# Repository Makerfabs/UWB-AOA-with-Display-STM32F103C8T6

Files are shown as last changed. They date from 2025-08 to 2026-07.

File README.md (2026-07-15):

# UWB-AOA-with-Display-STM32F103C8T6

UWB AOA with Display STM32F103C8T6

# Makerfabs

[Makerfabs Homepage](https://www.makerfabs.com/)

[Makerfabs Wiki](https://wiki.makerfabs.com/)

# Feature:

• Controller: STM32F103C8T6, max 72MHz frequency, 1.25 DMIPS/MHz(Dhrystone 2.1), 64KB Flash memory, 20KB SRAM  

• DW3000 Module(Anchor):UWB-X3-AOA  

• DW3000 Module(Tag):UWB-X3-MAX  

• OLED: 1.3" SSD1306, 128X64, I2C  

• "Zero" Dropout: On board ideal diode circuit  

• Dual-USB Type C:USB-Native/USB-TTL  

• USB-to-UART: CH340K  

• Charger: TP4056  

• Button:RST/BTN  

• Expander: 2X12 2.54mm header  

• Open Source: hardware/firmware/software  

• Coverage radius: 30m@6.8M 

• angle:+/-60° 

• angle error:±5° 

• Ranging error:< 10cm 

• Positioning error： <10cm 

• Frequency: CH5 (6.5 GHz)/CH9 (8 GHz)  

• Speed rate: 850 Kbps/6.8Mbps  

• Communication interface: SPI  

• Power Supply: USB 5.0V or 3.7V lithium battery  

# Usage:

1. Insert to USB-NATIVE port of AOA anchor.  
2. Insert to USB-TTL port of AOA tag(Or Powered by Li-battery).  
3. Open the AOA System Application.  
4. Select Tag ID and joined.  
5. Result Show:  
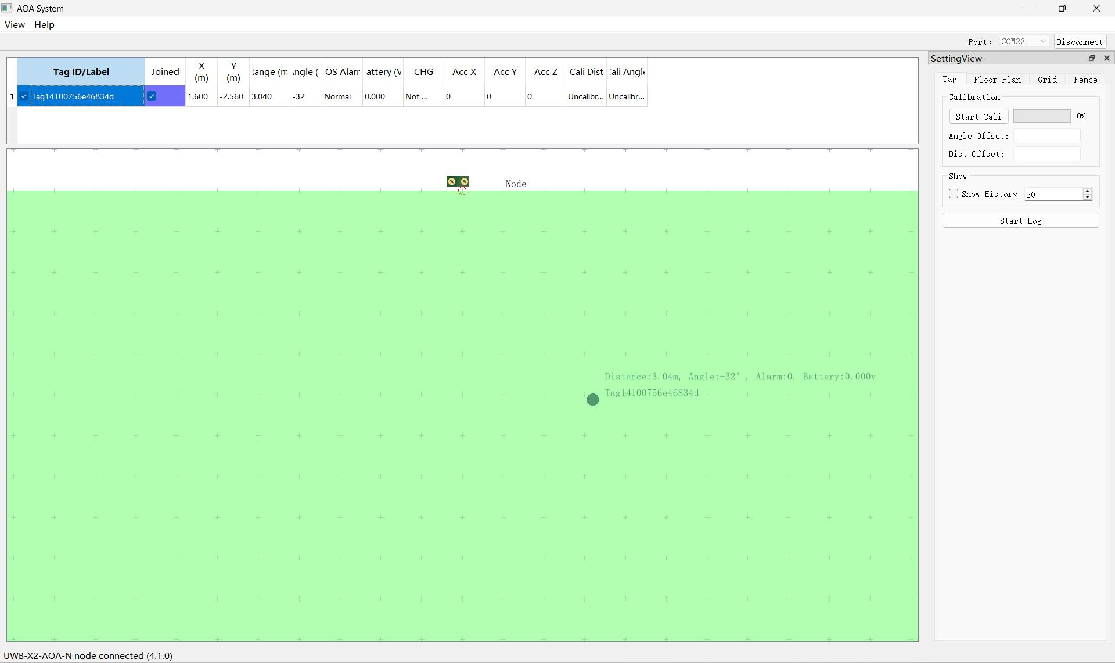
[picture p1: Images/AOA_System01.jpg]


# Firmware

| Type | Default Firmware | 
|---|---|
| Anchor | Project\_Anchor\_v1.0.hex |
| Tag | Project\_Tag\_v1.0.hex |

# How to Program?

|ST-LINK V2 |AOA Anchor/Tag Board|  
| ---- | ---- |
|SWCLK|SWCK|  
|SWDIO|SWIO|  
|GND|GND|  
|3.3V|+3.3V|  

# How to turn on the PA in tag?
1. Modify the value of PMSC_TXFINESEQ_DISABLE to 0x0d20010 in deca_vals.h header file: 

#define PMSC_TXFINESEQ_DISABLE  0x0d20010 

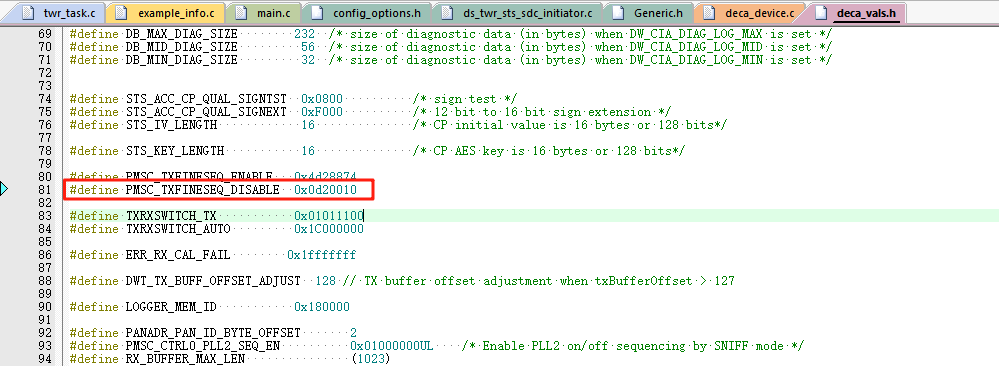
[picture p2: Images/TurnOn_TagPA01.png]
  

2. Add a definition in config_options.h header file: 

#define HW_PA 

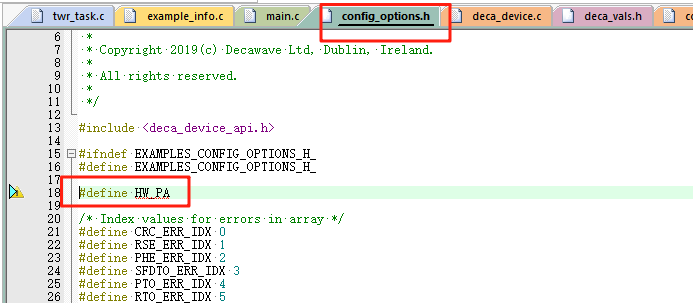
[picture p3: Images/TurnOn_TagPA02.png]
  

# Why there is No com port in AOA system software?  

1. Install the STM32_VCP_V1.4.0_Setup.exe in Driver folder.  
2. Update the driver from the Device Manager.  
3. Insert the USB Type C cable to USB Native port of AOA Anchor before you open the AOA system software. 

# Where to purchase? 
[AOA KIT](https://www.makerfabs.com/mauwb-stm32-aoa-development-kit.html) 

# FAQ

You can list your question here or contact techsupport@makerfabs.com for technology support. Detailed descriptions of your question will be helped to solve your question.

• Q:The AOA kit has multiple tag bindings, resulting in the inability to obtain distance and angle information.

• A:One AOA device only supports one anchor point paired with one tag to work simultaneously. Excess tags will cause the data not to be displayed. Please unbind the phantom false tags in the interface, and the kit can be used normally.

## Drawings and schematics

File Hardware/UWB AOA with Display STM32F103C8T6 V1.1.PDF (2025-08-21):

USB | Ideal Diode | OLED

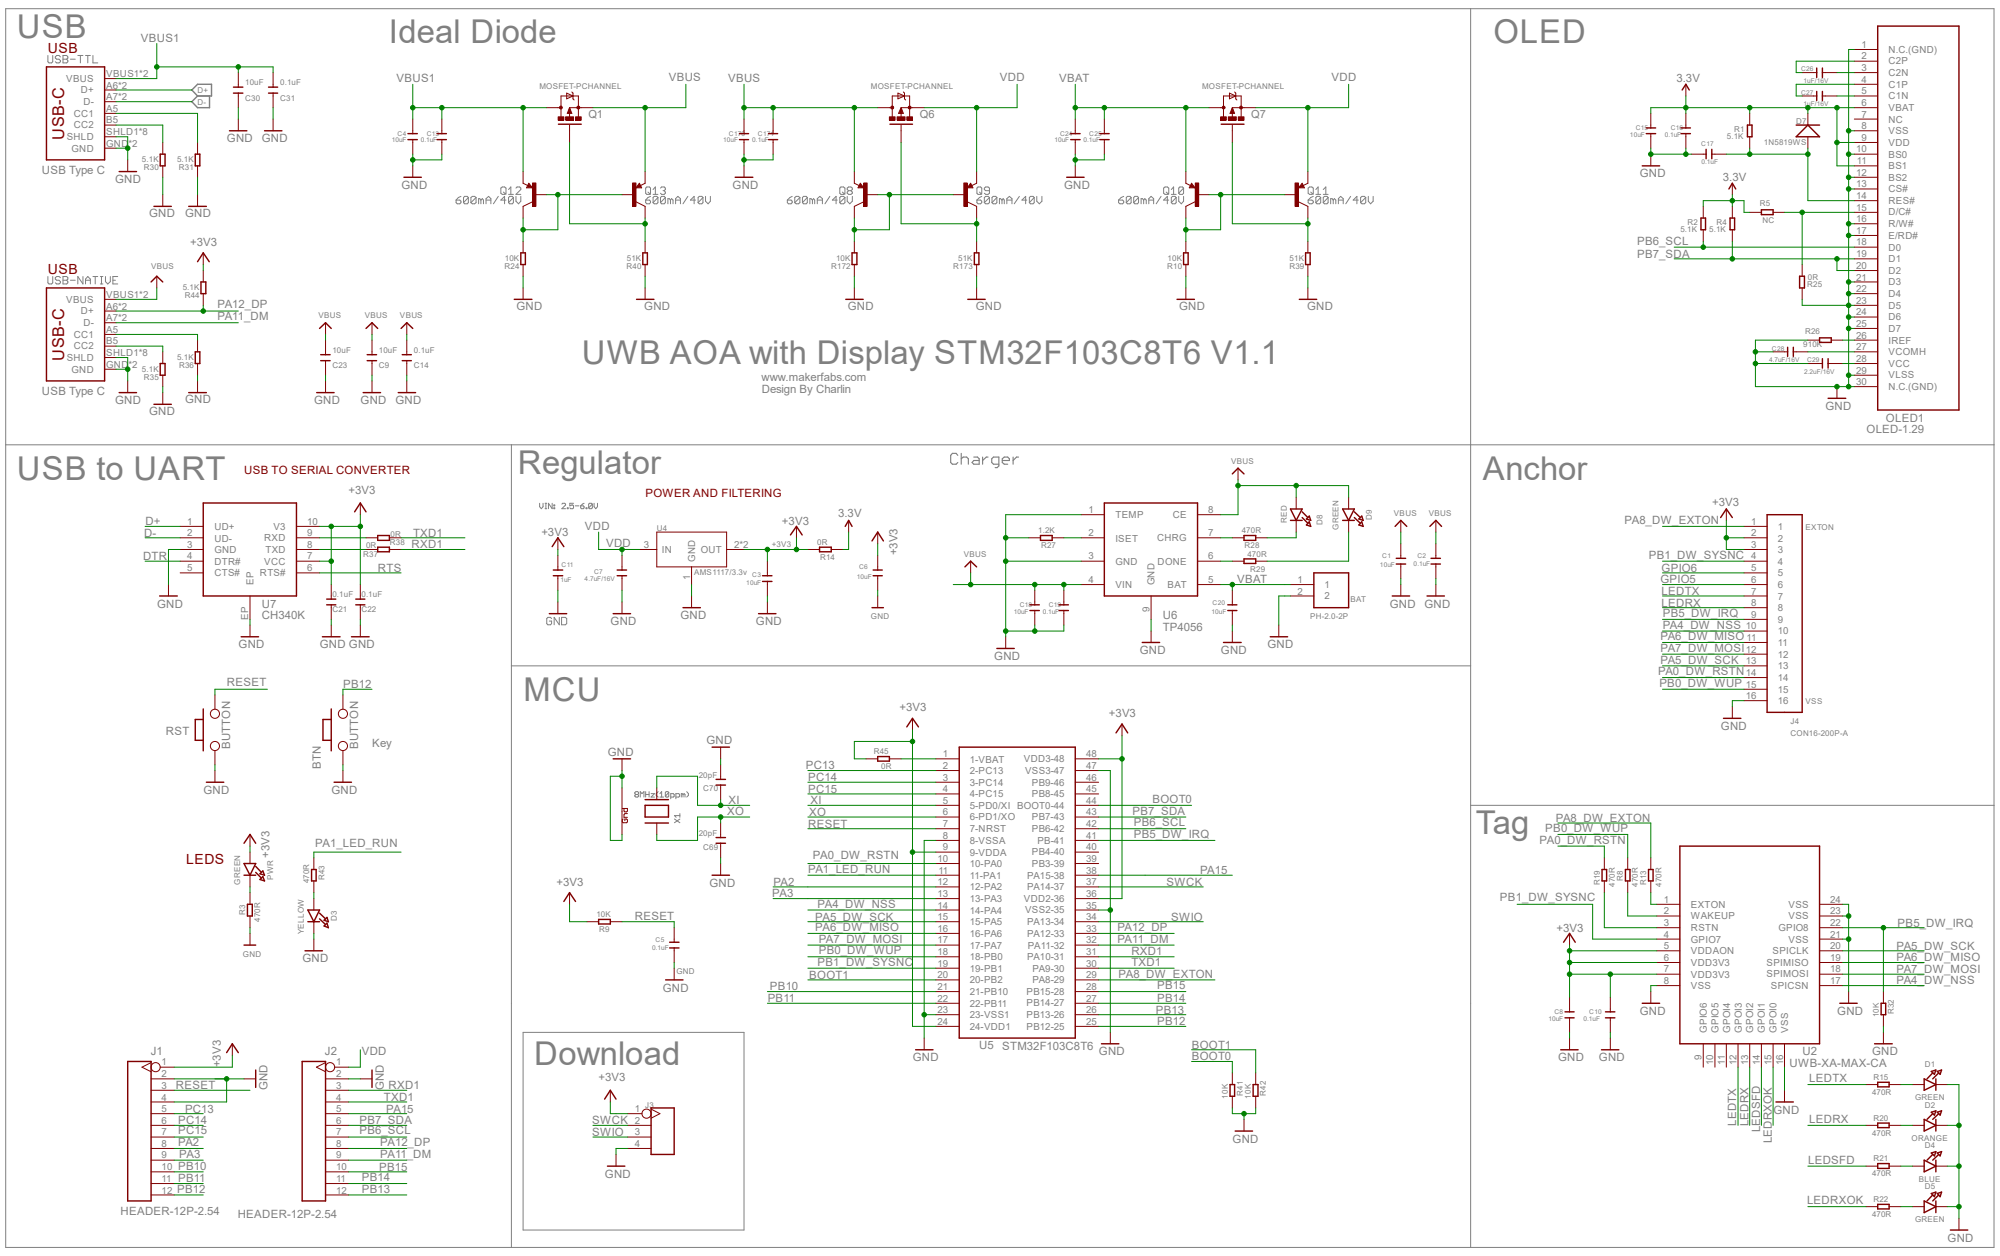
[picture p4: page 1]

VBUS1

USB TO SERIAL CONVERTER USB⁻C USB⁻C

D1 19
D2 20

UWB AOA with Display STM32F103C8T6 V1.1

4.7uF/16V C29 | VCC 28

2.2uF/16V | VLSS 29

11 PB11 | PB14 11
12 PB12 | 12 PB13

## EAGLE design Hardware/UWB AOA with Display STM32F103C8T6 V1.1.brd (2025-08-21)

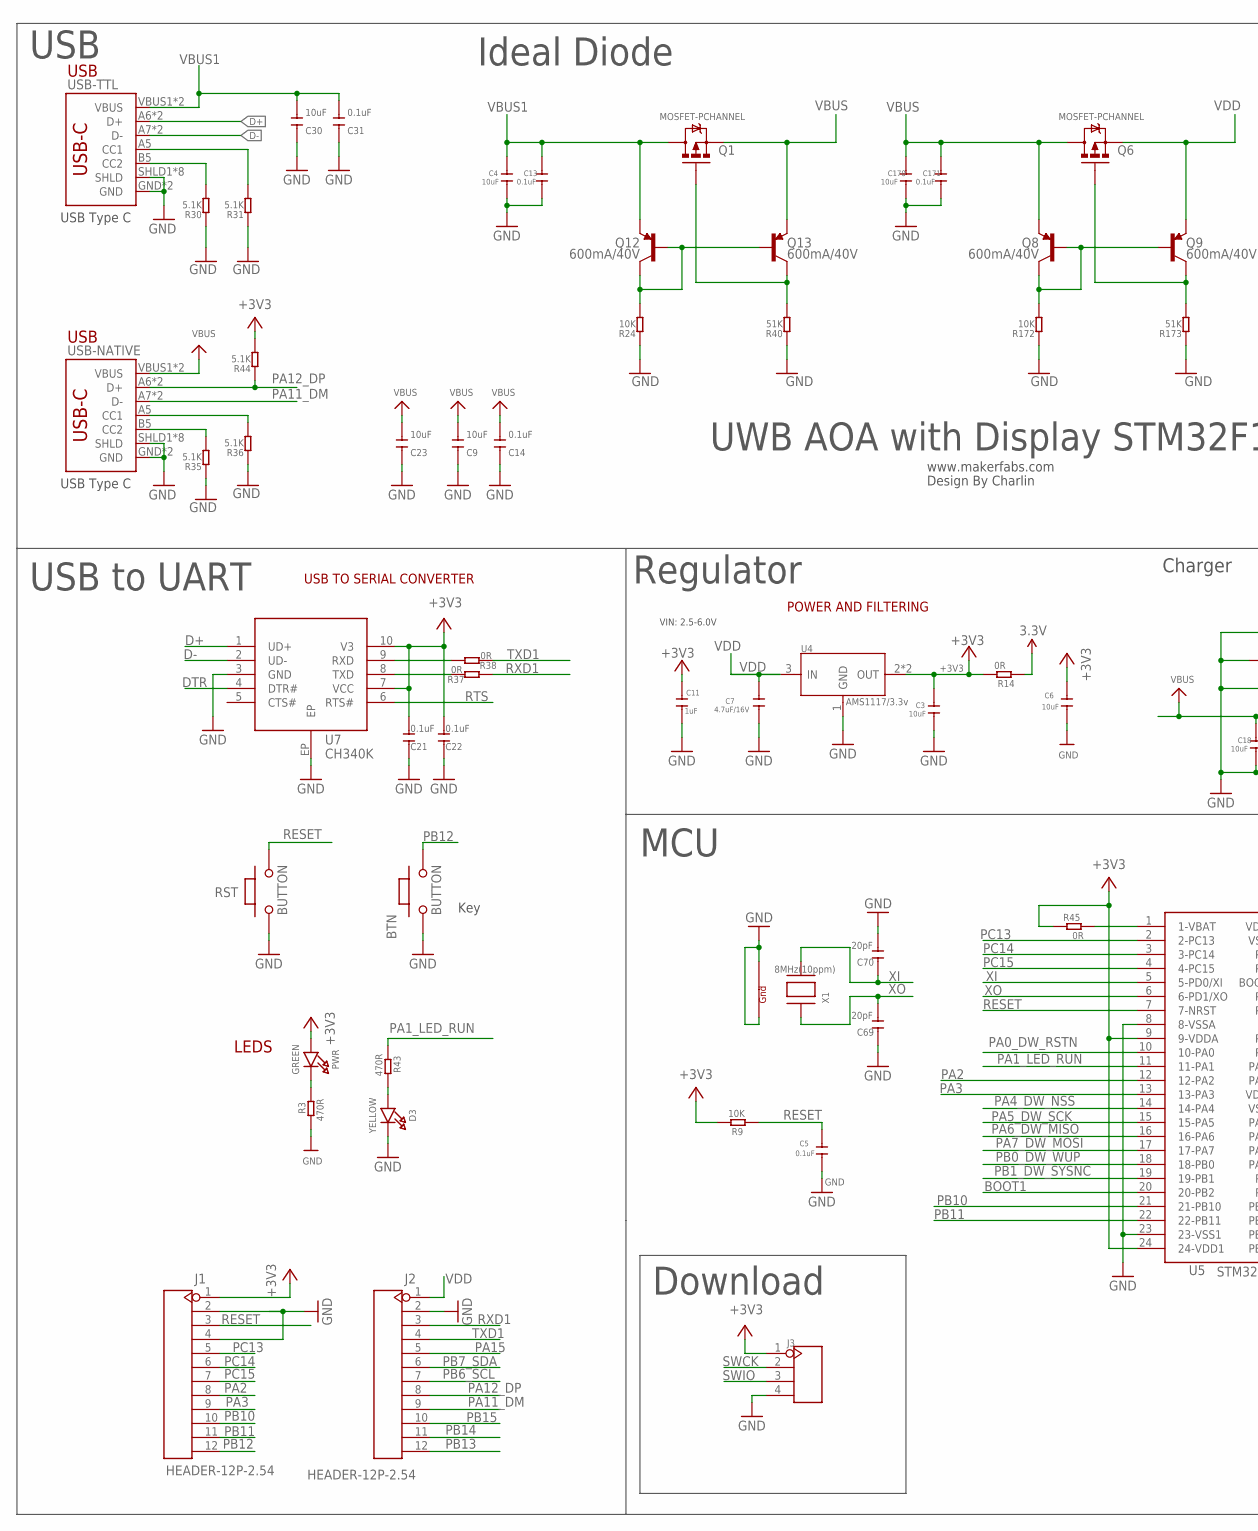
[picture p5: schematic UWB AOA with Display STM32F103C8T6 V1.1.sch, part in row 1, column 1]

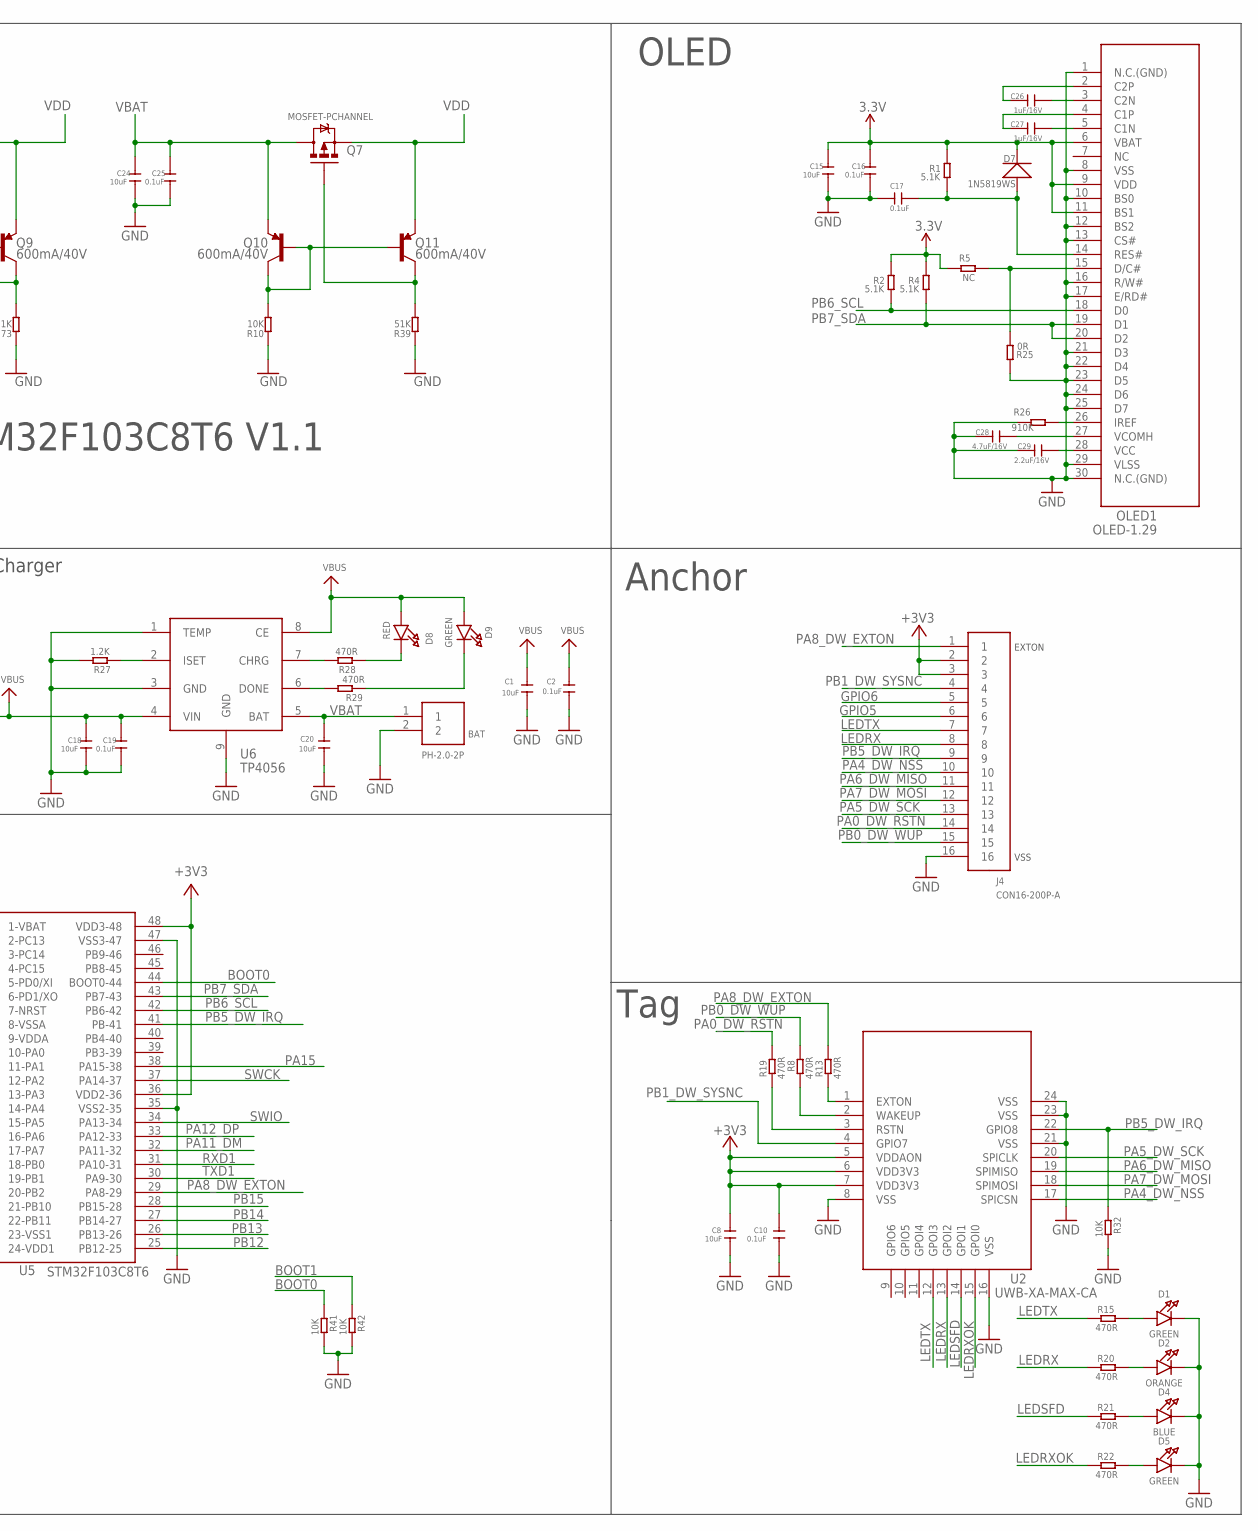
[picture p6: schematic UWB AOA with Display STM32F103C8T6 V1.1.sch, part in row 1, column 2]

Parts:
BAT: PH-2.0-2P
BTN: BUTTON; 157SW
C1, C3, C4, C6, C8, C15, C18, C20, C24, C170: 10uF; C0603
C2, C5, C10, C13, C16, C17, C19, C25, C171: 0.1uF; C0603
C7, C28: 4.7uF/16V; C0603
C9, C23, C30: 10uF; DISCRETE_C0603
C11: 1uF; C0603
C14, C21, C22, C31: 0.1uF; DISCRETE_C0603
C26, C27: 1uF/16V; C0603
C29: 2.2uF/16V; C0603
C69, C70: 20pF; DISCRETE_C0402
D1, D5, D9: GREEN; CHIPLED_0805_NOOUTLINE
D2: ORANGE; CHIPLED_0805_NOOUTLINE
D3: YELLOW; CHIPLED_0805_NOOUTLINE
D4: BLUE; CHIPLED_0805_NOOUTLINE
D7: 1N5819WS; SOD323
D8: RED; CHIPLED_0805_NOOUTLINE
J1, J2: HEADER-12P-2.54; 12P-2.54
J3: HEADER-4P-60/35MILROUND; 4P-65/35ROUND
J4: CON16-200P-A; THD16-200P-3250L240W430H
OLED1: OLED-1.29
PWR: GREEN; CHIPLED_0805_NOOUTLINE
Q1, Q6, Q7: MOSFET-PCHANNEL; SOT23-3
Q8, Q9, Q10, Q11, Q12, Q13: 600mA/40V; SOT23-3
R1, R2, R4: 5.1K; R0603
R3, R8, R13, R15, R19, R20, R21, R22, R28, R29, R43: 470R; R0603
R5: NC; R0603
R9, R32, R41, R42: 10K; R0603
R10, R24, R172: 10K; DISCRETE_R0603
R14, R25, R37, R38, R45: 0R; R0603
R26: 910K; R0603
R27: 1.2K; R0603
R30, R31, R35, R36, R44: 5.1K; DISCRETE_R0603
R39, R40, R173: 51K; DISCRETE_R0603
RST: BUTTON; 157SW
U2: UWB-XA-MAX-CA; UWB-X1-MAK-CA
U4: AMS1117/3.3v; SOT89
U5: STM32F103C8T6; LQFP48-50P-900L900W160H
U6: TP4056; SOP8-1.27P
U7: CH340K; ESOP-10-EP-150MIL
USB-NATIVE: USB_C5; USB-C-16P-5
USB-TTL: USB_C5; USB-C-16P-5
X1: 8MHz(10ppm); NX3225

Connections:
3.3V: C15.1, C16.1, D7.-, OLED1.6 (VBAT), OLED1.9 (VDD), OLED1.11 (BS1), R1.2, R2.2, R4.2, R5.2, R14.1
+3V3: C3.1, C6.1, C8.1, C10.1, C11.1, C21.2, C22.2, J1.1, J3.1, J4.2, J4.3, PWR.A, R9.2, R14.2, R44.2, R45.1, U2.5 (VDDAON), U2.6 (VDD3V3), U2.7 (VDD3V3), U4.2 (OUT), U4.4 (OUT), U5.9 (9-VDDA), U5.24 (24-VDD1), U5.36 (VDD2-36), U5.48 (VDD3-48), U7.7 (VCC), U7.10 (V3)
BOOT0: R41.1, U5.44 (BOOT0-44)
BOOT1: R42.1, U5.20 (20-PB2)
D+: U7.1 (UD+), USB-TTL.A6 (D+), USB-TTL.B6 (D+)
D-: U7.2 (UD-), USB-TTL.A7 (D-), USB-TTL.B7 (D-)
DTR: U7.4 (DTR#)
GND: BAT.2, BTN.1, C1.2, C2.2, C3.2, C4.2, C5.2, C6.2, C7.2, C8.2, C9.1, C10.2, C11.2, C13.2, C14.1, C15.2, C16.2, C17.1, C18.2, C19.2, C20.2, C21.1, C22.1, C23.1, C24.2, C25.2, C28.1, C29.1, C30.1, C31.1, C69.2, C70.1, C170.2, C171.2, D1.C, D2.C, D3.C, D4.C, D5.C, J1.2, J1.4, J2.2, J3.4, J4.16, OLED1.1 (N.C.(GND)), OLED1.8 (VSS), OLED1.10 (BS0), OLED1.12 (BS2), OLED1.13 (CS#), OLED1.16 (R/W#), OLED1.17 (E/RD#), OLED1.21 (D3), OLED1.22 (D4), OLED1.23 (D5), OLED1.24 (D6), OLED1.25 (D7), OLED1.29 (VLSS), OLED1.30 (N.C.(GND)), R3.1, R10.1, R24.1, R25.2, R26.2, R27.2, R30.1, R31.1, R32.2, R35.1, R36.1, R39.1, R40.1, R41.2, R42.2, R172.1, R173.1, RST.1, U2.8 (VSS), U2.16 (VSS), U2.21 (VSS), U2.23 (VSS), U2.24 (VSS), U4.1 (GND), U5.8 (8-VSSA), U5.23 (23-VSS1), U5.35 (VSS2-35), U5.47 (VSS3-47), U6.1 (TEMP), U6.3 (GND), U6.9 (GND), U7.3 (GND), U7.EP, USB-NATIVE.GND, USB-NATIVE.GND2 (GND), USB-NATIVE.SHLD1 (SHLD), USB-NATIVE.SHLD2 (SHLD), USB-NATIVE.SHLD3 (SHLD), USB-NATIVE.SHLD4 (SHLD), USB-NATIVE.SHLD5 (SHLD), USB-NATIVE.SHLD6 (SHLD), USB-NATIVE.SHLD7 (SHLD), USB-NATIVE.SHLD8 (SHLD), USB-TTL.GND, USB-TTL.GND2 (GND), USB-TTL.SHLD1 (SHLD), USB-TTL.SHLD2 (SHLD), USB-TTL.SHLD3 (SHLD), USB-TTL.SHLD4 (SHLD), USB-TTL.SHLD5 (SHLD), USB-TTL.SHLD6 (SHLD), USB-TTL.SHLD7 (SHLD), USB-TTL.SHLD8 (SHLD), X1.2 (G2), X1.4 (G1)
GPIO5: J4.6
GPIO6: J4.5
LEDRX: J4.8, R20.1, U2.13 (GPOI2)
LEDRXOK: R22.1, U2.15 (GPOI0)
LEDSFD: R21.1, U2.14 (GPOI1)
LEDTX: J4.7, R15.1, U2.12 (GPOI3)
unnamed: D1.A, R15.2
unnamed: C17.2, D7.+, OLED1.14 (RES#), R1.1
unnamed: OLED1.15 (D/C#), R5.1, R25.1
unnamed: PWR.C, R3.2
unnamed: C28.2, OLED1.27 (VCOMH)
unnamed: C26.2, OLED1.3 (C2N)
unnamed: C29.2, OLED1.28 (VCC)
unnamed: OLED1.26 (IREF), R26.1
unnamed: R13.1, U2.1 (EXTON)
unnamed: R8.1, U2.2 (WAKEUP)
unnamed: R19.1, U2.3 (RSTN)
unnamed: Q10.1 (B), Q10.3 (C), Q11.1 (B), R10.2
unnamed: D2.A, R20.2
unnamed: D4.A, R21.2
unnamed: D5.A, R22.2
unnamed: C26.1, OLED1.2 (C2P)
unnamed: C27.1, OLED1.4 (C1P)
unnamed: C27.2, OLED1.5 (C1N)
unnamed: R27.1, U6.2 (ISET)
unnamed: D3.A, R43.2
unnamed: R31.2, USB-TTL.A5 (CC1)
unnamed: R30.2, USB-TTL.B5 (CC2)
unnamed: R45.2, U5.1 (1-VBAT)
unnamed: R28.2, U6.7 (CHRG)
unnamed: R29.2, U6.6 (DONE)
unnamed: D8.C, R28.1
unnamed: D9.C, R29.1
unnamed: R36.2, USB-NATIVE.A5 (CC1)
unnamed: R35.2, USB-NATIVE.B5 (CC2)
unnamed: Q7.1 (G), Q11.3 (C), R39.2
unnamed: Q12.1 (B), Q12.3 (C), Q13.1 (B), R24.2
unnamed: Q1.1 (G), Q13.3 (C), R40.2
unnamed: R38.2, U7.9 (RXD)
unnamed: R37.2, U7.8 (TXD)
unnamed: Q8.1 (B), Q8.3 (C), Q9.1 (B), R172.2
unnamed: Q6.1 (G), Q9.3 (C), R173.2
PA0_DW_RSTN: J4.14, R19.2, U5.10 (10-PA0)
PA1_LED_RUN: R43.1, U5.11 (11-PA1)
PA2: J1.8, U5.12 (12-PA2)
PA3: J1.9, U5.13 (13-PA3)
PA4_DW_NSS: J4.10, U2.17 (SPICSN), U5.14 (14-PA4)
PA5_DW_SCK: J4.13, U2.20 (SPICLK), U5.15 (15-PA5)
PA6_DW_MISO: J4.11, U2.19 (SPIMISO), U5.16 (16-PA6)
PA7_DW_MOSI: J4.12, U2.18 (SPIMOSI), U5.17 (17-PA7)
PA8_DW_EXTON: J4.1, R13.2, U5.29 (PA8-29)
PA11_DM: J2.9, U5.32 (PA11-32), USB-NATIVE.A7 (D-), USB-NATIVE.B7 (D-)
PA12_DP: J2.8, R44.1, U5.33 (PA12-33), USB-NATIVE.A6 (D+), USB-NATIVE.B6 (D+)
PA15: J2.5, U5.38 (PA15-38)
PB0_DW_WUP: J4.15, R8.2, U5.18 (18-PB0)
PB1_DW_SYSNC: J4.4, U2.4 (GPIO7), U5.19 (19-PB1)
PB5_DW_IRQ: J4.9, R32.1, U2.22 (GPIO8), U5.41 (PB-41)
PB6_SCL: J2.7, OLED1.18 (D0), R2.1, U5.42 (PB6-42)
PB7_SDA: J2.6, OLED1.19 (D1), OLED1.20 (D2), R4.1, U5.43 (PB7-43)
PB10: J1.10, U5.21 (21-PB10)
PB11: J1.11, U5.22 (22-PB11)
PB12: BTN.2, J1.12, U5.25 (PB12-25)
PB13: J2.12, U5.26 (PB13-26)
PB14: J2.11, U5.27 (PB14-27)
PB15: J2.10, U5.28 (PB15-28)
PC13: J1.5, U5.2 (2-PC13)
PC14: J1.6, U5.3 (3-PC14)
PC15: J1.7, U5.4 (4-PC15)
RESET: C5.1, J1.3, R9.1, RST.2, U5.7 (7-NRST)
RTS: U7.6 (RTS#)
RXD1: J2.3, R37.1, U5.31 (PA10-31)
SWCK: J3.2, U5.37 (PA14-37)
SWIO: J3.3, U5.34 (PA13-34)
TXD1: J2.4, R38.1, U5.30 (PA9-30)
VBAT: BAT.1, C20.1, C24.1, C25.1, Q7.3 (D), Q10.2 (E), U6.5 (BAT)
VBUS: C1.1, C2.1, C9.2, C14.2, C18.1, C19.1, C23.2, C170.1, C171.1, D8.A, D9.A, Q1.2 (S), Q6.3 (D), Q8.2 (E), Q13.2 (E), U6.4 (VIN), U6.8 (CE), USB-NATIVE.VBUS1 (VBUS), USB-NATIVE.VBUS2 (VBUS)
VBUS1: C4.1, C13.1, C30.2, C31.2, Q1.3 (D), Q12.2 (E), USB-TTL.VBUS1 (VBUS), USB-TTL.VBUS2 (VBUS)
VDD: C7.1, J2.1, Q6.2 (S), Q7.2 (S), Q9.2 (E), Q11.2 (E), U4.3 (IN)
XI: C70.2, U5.5 (5-PD0/XI), X1.3 (X2)
XO: C69.1, U5.6 (6-PD1/XO), X1.1 (X1)

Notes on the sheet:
Anchor
LEDS
POWER AND FILTERING
Key
UWB AOA with Display STM32F103C8T6 V1.1
VIN: 2.5-6.0V
USB
USB Type C
USB TO SERIAL CONVERTER
USB to UART
Tag
OLED
Charger
Ideal Diode
MCU
Regulator
Download
www.makerfabs.com
Design By Charlin

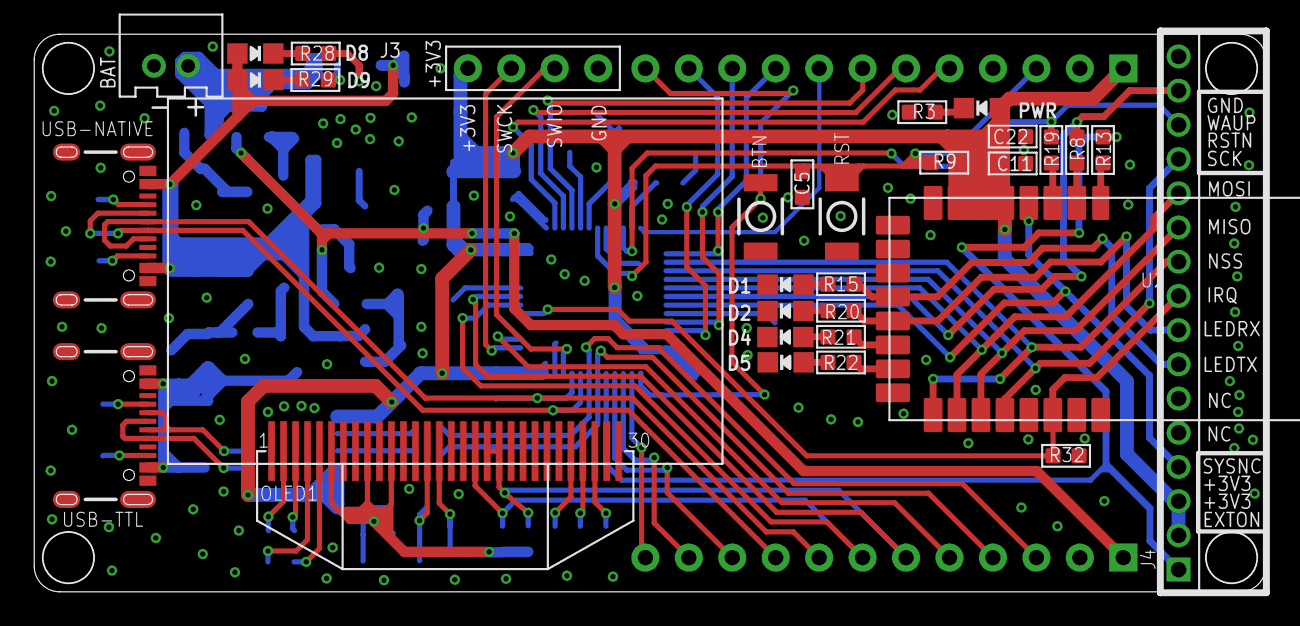
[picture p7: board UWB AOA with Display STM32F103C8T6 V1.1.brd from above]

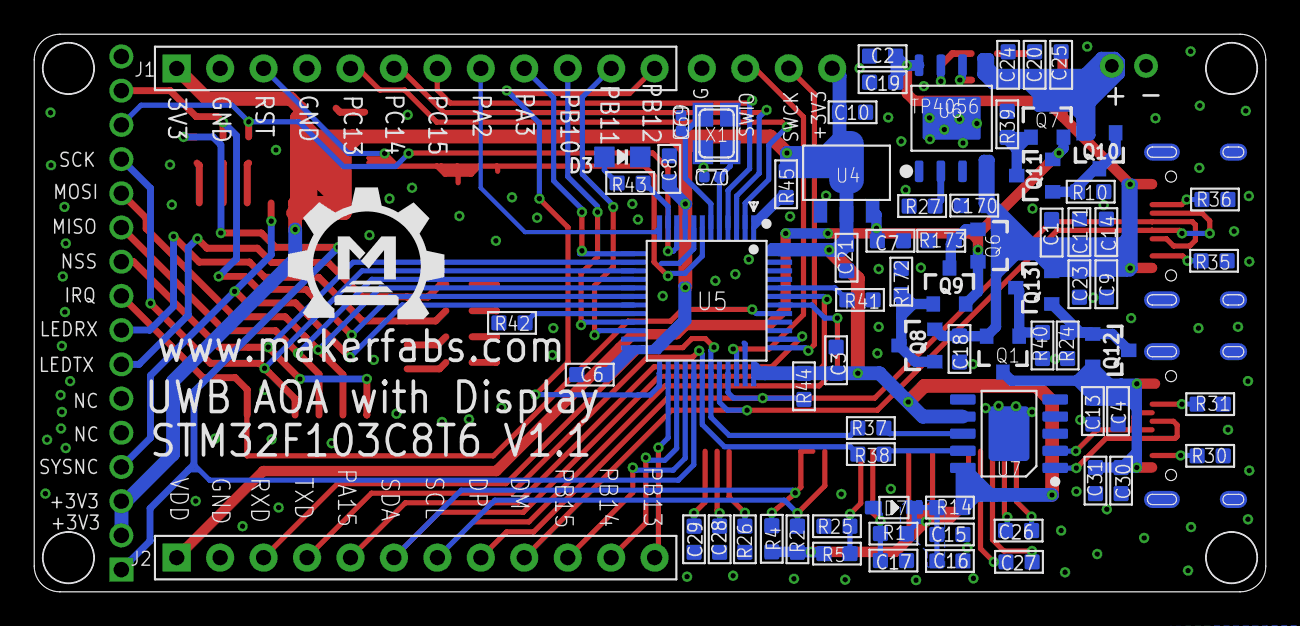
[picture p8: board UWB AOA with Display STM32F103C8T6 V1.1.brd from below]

Board: 2 copper layers, 72.0 x 32.6 mm, 106 parts (75 on the bottom side), 84 nets.

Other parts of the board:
U$1: MAKERFABS_0.3

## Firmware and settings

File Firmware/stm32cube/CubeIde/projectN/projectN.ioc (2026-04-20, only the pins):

Mcu.UserName=STM32F103C8Tx
PA1.GPIO_Label=LED0
PA1.Signal=GPIO_Output
PA10.Signal=USART1_RX
PA11.Signal=USB_DM
PA12.Signal=USB_DP
PA13.Signal=SYS_JTMS-SWDIO
PA14.Signal=SYS_JTCK-SWCLK
PA4.GPIO_Label=DW1000_CS
PA4.Signal=GPIO_Output
PA5.Signal=SPI1_SCK
PA6.Signal=SPI1_MISO
PA7.Signal=SPI1_MOSI
PA9.Signal=USART1_TX
PB5.Signal=GPXTI5
PB6.Signal=I2C1_SCL
PB7.Signal=I2C1_SDA
PC14-OSC32_IN.Signal=RCC_OSC32_IN
PC15-OSC32_OUT.Signal=RCC_OSC32_OUT
PD0-OSC_IN.Signal=RCC_OSC_IN
PD1-OSC_OUT.Signal=RCC_OSC_OUT

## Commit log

2025-08-21 Add hardware/Firmware/software
    [UWB AOA with Display STM32F103C8T6 V1.1.brd, UWB AOA with Display STM32F103C8T6 V1.1.sch]
2025-08-22 Add STM32 Virtual Com Port Driver and CH340 Driver
2026-01-22 add stm32cubeide project code
2026-04-20 Add cube code
    [led_demo Debug.cfg]

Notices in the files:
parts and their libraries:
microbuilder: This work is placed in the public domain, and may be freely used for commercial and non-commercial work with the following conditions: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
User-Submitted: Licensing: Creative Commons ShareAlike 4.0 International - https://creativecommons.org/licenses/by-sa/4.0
